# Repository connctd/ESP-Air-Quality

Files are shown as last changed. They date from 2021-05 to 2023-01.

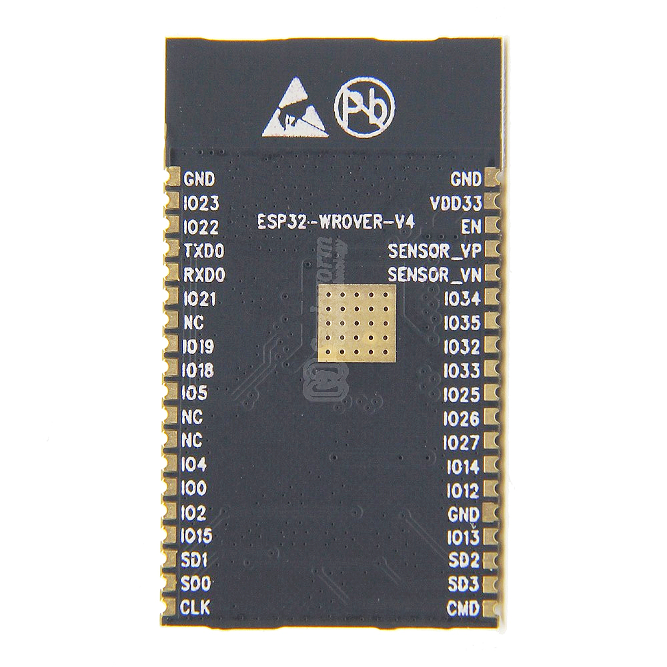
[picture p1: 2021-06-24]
hardware/ESP32-WROVER_pinout.jpeg

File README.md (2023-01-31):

# Airlytics Frame Manual

## Starting Sequence

After the system has been  powered up it tries to establish a connection with the WLAN. If a connection could be established, the first LED flashes green. If this was not possible, for example because no WiFi has been configured yet, the first LED lights up blue permanently and the System awaits to setup Wifi credentials (See setting up Wifi)

Afterwards, the sensor configuration is shown by the first 4 LEDs of the LED ring:

- First LED green, SCD30 installed and ready, otherwise white.
- Second LED green, BME680 installed and ready, otherwise white
- Third LED green, BME280 installed and ready, otherwise white
- Fourth LED green, SPS30 installed and ready, otherwise white

If all 4 LEDs are white, no sensor is installed or was found.

If the BME680 sensor is installed, it must first be adjusted so that usable values can be measured. This process can take up to 10min at the first start. If the calibration was completed successfully, it will not take so much time in the future. 

The same applies to the temperature values; these sensors generally need up to 15 minutes before the values reach their high precision.

## Setting Up the WiFi

When the system starts, it tries to connect to wifi which is indicated by an orange led. If ut cannot connect to the WIFI or no WIFI is configured yet, it automatically goes into the WIFI configuration mode, recognizable by a blue LED. You can also start the configuration mode manually by pressing and holding the button on the back for 5 seconds until the first LED lights up green. Then connect the smartphone (or PC) to the Network with the SSID "AirLytics Frame". You will be prompted to "Register to network". Follow this prompt and you will get to the configuration menu. Select the network from the list and enter the password, then press "Save". The system restarts and tries to log in to the network. If this is successful, the first LED flashes green, otherwise the network configuration starts over again and the steps must be repeated.

## Factory Reset
In order to reset the device to it's factory settings, the button on the back must be pressed for at least 15s. 

After 5s the first LED will light up green, after 12s it will light up red. After 15s it will blink red and the device will perform a factory reset. This will delete the network settings and the sensor settings like calibration data. 

# Error Handling

## Error Color Codes

Whenever an error occurs that was identified by the program, either the first LED or the gauge will blink 3 times in red color. Afterwards the first led or the whole gauge represents the error type by showing a solid color.

### First led blinks red, afterwards it shows a solid color

Indicates connection or general system errors. The following color code might give further details on the error type. 

| color | error |
| :--- | :--- |
| white | Error not further specified |
| blue | Error has to do with Wifi Connection |
| orange | Marconi Client could not be initialized. IP address could not resolved from URL or kind like that. |
| violette | Marconi Session could not be established. |
| red | EEPROM failure |

### Gauge blinks red, afterwards shows solid color

Indicates errors related to the connected sensors.

| color | error |
| :--- | :--- |
| white | Error not further specified |
| yellow | ERROR BME280 |
| orange | Error BME680 |
| violette | Error BSEC library |

# Airlytics Frame Debug Mode

The firmware (AirLyticsFrame_ESP/AirLyticsFrame_ESP.ino) has a debug flag. Setting it to true the errors described above will be more obvious (whole ring flashes). Also the frame reports property updates every 30s in debug mode. In normal mode the frame only reports updates every 2 minutes.

# Airlytics Frame Development

This section explains the development of the Airlytics firmware for an ESP32 with the Arduino IDE.   

There are 3 Arduino projects in this repository:
| Arduino Project | Description |
| :--- | :--- |
| Config-Flasher/Config-Flasher.ino | Software to flash device credentials (id and key) to the ESP32 EEPROM |
| SCD30_Calibration/SCD30_Calibration.ino | Software to calibrate the CO2 Sensor (SCD30) |
| AirLyticsFrame_ESP/AirLyticsFrame_ESP.ino | Firmware of the AirLytics Frame |

## Board Management

In order to install ESP32 extension to the Arduino IDE, add the line ```https://raw.githubusercontent.com/espressif/arduino-esp32/gh-pages/package_esp32_index.json``` to the additional board manager URL in the Arduino Settings. 

Open the Board Management and search for ```esp32```. Choose the version ```1.0.6``` developed by Espressif Systems and hit install. 

## Libraries

All libraries (except connctd Marconi) could be installed via the Library Management of Arduino IDE. In the menu bar go to ```Tools->Manage Libraries...``` and install the libraries below: 

| library | version | link |
| :--- | :--- | :--- |
| Wifi Manager | 2.0.4-beta  | https://github.com/tzapu/WiFiManager |
| Fast LED | 3.4.0 | https://github.com/FastLED/FastLED |
| Adafruit Unified Sensor | 1.1.4 | https://github.com/adafruit/Adafruit_Sensor |
| Adafruit BME280 | 2.1.3 | https://github.com/adafruit/Adafruit_BME280_Library |
| Adafruit SCD30 | 1.0.7 | https://github.com/adafruit/Adafruit_SCD30 |
| Bosh Sensortec | 1.6.1480 | https://github.com/BoschSensortec/BSEC-Arduino-library |
| connctd Marconi | | https://github.com/connctd/marconi-lib |
| ChaCha (marconi dep) | | https://github.com/OperatorFoundation/Crypto |
| ESP Coap (marconi dep)  | | https://github.com/connctd/ESP-CoAP |
| Sensirion SPS30 | 1.0.0 | https://github.com/Sensirion/arduino-sps |

### Installing connctd Marconi library

If you do not have git installed on your machine, please open the browser and and go to the [github page](https://github.com/connctd/marconi-lib). Press on ```Code``` and download the ZIP file. Extract the content to your Arduino libraries folder and restart Arduino IDE again. The macroni library shall now be available. 

If you have git installed, navigate to your Arduino IDE libraries folder and run the following command ```git clone https://github.com/connctd/marconi-lib```

### Modify platform.txt

The bsec library expects certain flags during compilation like mentioned here: https://github.com/BoschSensortec/BSEC-Arduino-library#3-modify-the-platformtxt-file Checkout the instructions. Alternatively you can do the following (but we cant guarantee that it works like that with later versions):

For **MacOS**, go to folder `~/Library/Arduino15/packages/esp32/hardware/esp32/1.0.6` and open `platform.txt`. Search for line

```
recipe.c.combine.pattern="{compiler.path}{compiler.c.elf.cmd}" {compiler.c.elf.flags} {compiler.c.elf.extra_flags} {compiler.libraries.ldflags} -Wl,--start-group {object_files} "{archive_file_path}" {compiler.c.elf.libs} {build.extra_libs} -Wl,--end-group -Wl,-EL -o "{build.path}/{build.project_name}.elf"
```

and change it to

```
recipe.c.combine.pattern="{compiler.path}{compiler.c.elf.cmd}" {compiler.c.elf.flags} {compiler.c.elf.extra_flags} -Wl,--start-group {object_files} "{archive_file_path}" {compiler.c.elf.libs} {compiler.libraries.ldflags} -Wl,--end-group -Wl,-EL -o "{build.path}/{build.project_name}.elf"
```

On **Windows** open: `c:\Users\YOURUSERNAME\AppData\Local\Arduino15\packages\esp32\hardware\esp32\1.0.6` and search for line starting with `recipe.c.combine.pattern`. In that line search for `-Wl`. Before that string add the following: `{compiler.libraries.ldflags}`. Resulting line should look like `recipe.c.combine.pattern [...] {build.extra_libs} {compiler.libraries.ldflags} -Wl [...]`

## Flashing the device credentials

Each Airlytics ESP device needs to authenticate itself with the backend by using a specific and unique device ID as well as a secret key. This has to be written to the EEProm of the ESP before the firmware will be flahed. In order to write the device credentials to the ESP EEProm, open the file ```Config-Flasher/Config-Flasher.ino```. 

In the setup section of the code, search for the line ```//deviceConfig = (DeviceConfig){ "<device id>", {<device secret in hex bytes>}};```. replace ```<device id>``` with the device ID you want to flash (IDs will be generated by connctd). 

Your device secret has to handled as hex byte array. There are several ways to generate a hex array of the base64 key. An easy way is to copy your secret key, go to [cryptii](https://cryptii.com/pipes/base64-to-hex), paste your key on the left box (If you do not follow the link, choose Decode, Base64 and the RFC 3548 variant ). A byte array will be calculated on the right. Copy the byte array and replace it with ```<device secret in hex bytes>```. Be aware of the C++ syntax for hex declaration (0x). 

Your final line should look like this (no valid id and secret used for the example):

    deviceConfig = (DeviceConfig){ "mku63nztfw0gn043", {0x41, 0xc6, 0x03, 0x2e, 0x15, 0xc2, 0xa8, 0xc4, 0x5f, 0x98, 0x96, 0x99, 0xf4, 0x6d, 0x7f, 0x46, 0x66, 0x14, 0x0a, 0x98, 0xde, 0x18, 0x64, 0xb2, 0xe9, 0x77, 0x55, 0xba, 0xdd, 0x50, 0xf1, 0xcf}};``` 
  
Transfer the code to your ESP. In the Serial Monitor, you'll might see something like: 

    Initialize EEPROM
    generating DeviceConfig object
    DeviceConfig generated
    DeviceID = mku63nztfw0gn043
    Device Key = 41 C6 33 2E ...
    Save device configuration ... OK
    Checking device Id ... OK
    Checking Device Key ... OK

    And done... Bye!

## Flashing the Airlytics firmware

In case you do not have flashed your device with the ```device id``` and ```device secret``` yet, please follow the steps for flashing the device credentials. 

Open the File ```AirLyticsFrame_ESP/AirLyticsFrame_ESP.ino``` and transfer it to your ESP. 

Your device is ready to use. 

## Calibrating the SCD30 manually

The program ```SCD30_Calibration``` allows the manual calibration of SCD30 CO2 Sensors. In general, this sensor has already been calibrated by the manufacturer. However, it may happen that this calibration is no longer valid. 
 
 There are two ways of calibrating the SCD30 with this program
       - place the sensor in an environment (outsite) with a CO2 value around 400ppm, wait until the measured CO2 value stabilizes and press the button 
       - place the sensor in an environment with a known CO2 value, wait until the measured CO2 value stabilizes and send the reference value via Serial. 
 
 The command to force the calibration is ```#cal:<your co2 value>$``` where ```<your co2 value>``` has to be replaced by an integer value 
 representing the reference value for your calibration. Example: in order to calibrate the SCD30 with a reference of 600ppm, you have to
 send ```#cal:600$```.

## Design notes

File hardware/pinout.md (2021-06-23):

# Pin Usage

## LEDs

* DATA IO25 (I2S available on this pin to make handling WS2812 etc. easier)
* U3 can be used to switch level shifter and direct connect to IO25 for the LEDs

## BME680

* SDA IO21
* SCL IO22
* SD0 IO19
* CS IO18

## SCD30

* SDA IO21
* SCL IO22
* RDY IO15
* SEL IO4

## User Button

* Button IO14 (pulling low with 10k resistor, debounced with 100nF and 1k)

## Board LEDs

* LED1 RX for the serial programmer
* LED2 TX for the serial programmer
* LED3 power indicator for USB-VCC

## GPIO

Contains 9 additional GPIO, I2C, GND, 3.3V and 5V marked on the board

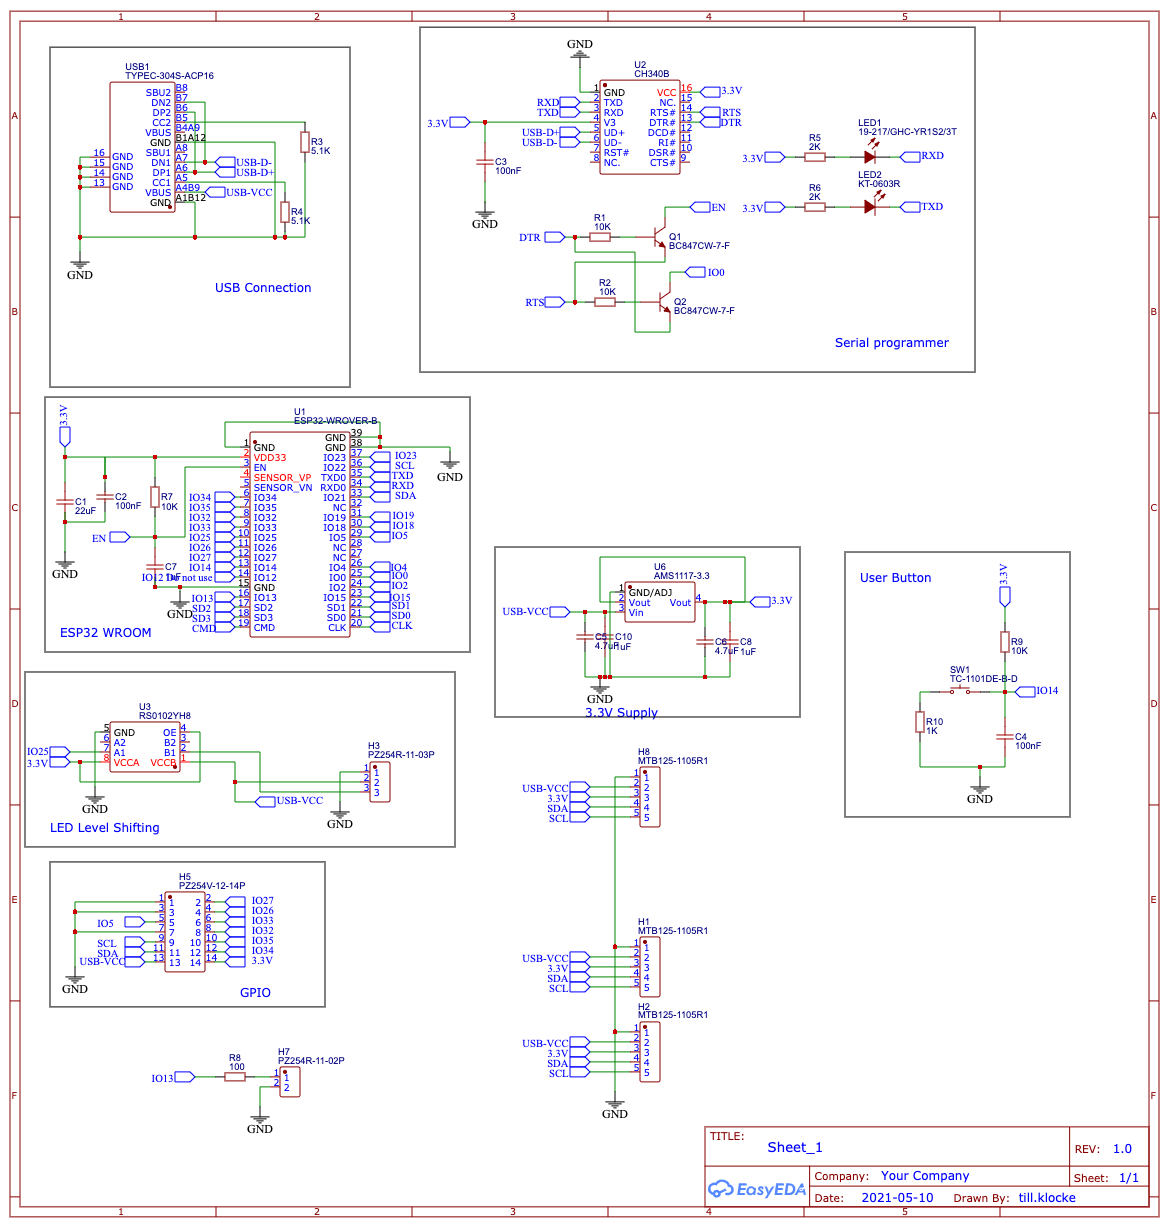
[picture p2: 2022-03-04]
hardware/Schematic.png

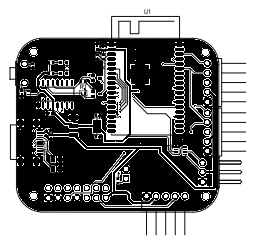
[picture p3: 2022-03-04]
hardware/pcb-image.png

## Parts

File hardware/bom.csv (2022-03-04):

ID | Name | Designator | Footprint | Quantity | Manufacturer Part | Manufacturer | Supplier | Supplier Part | Price
1 | MTB125-1105R1 | H1,H2,H8 | HDR-TH_5P-P2.54-H-M-W10.0 | 3 | MTB125-1105R1 | MINTRON | LCSC | C376123 | 0.037
2 | RS0102YH8 | U3 | SOT-23-8_L3.0-W1.7-P0.65-LS2.8-BL | 1 | RS0102YH8 | Jiangsu RUNIC Tech | LCSC | C783414 | 0.312
3 | PZ254R-11-02P | H7 | HDR-TH_2P-P2.54-H-M-W10.4 | 1 | PZ254R-11-02P | XFCN | LCSC | C492410 | 0.013
4 | 100 | R8 | R0402 | 1 | RC0402FR-07100RL | YAGEO | LCSC | C106232 | 0.001
5 | PZ254V-12-14P | H5 | HDR-TH_14P-P2.54-V-M-R2-C7-S2.54 | 1 | PZ254V-12-14P | XFCN | LCSC | C492424 | 0.073
6 | ESP32-WROVER-B | U1 | WIFIM-SMD_39P-L31.4-W18.0-P1.27 | 1 | ESP32-WROVER-B | Espressif Systems | LCSC | C503591 | 7.159
7 | TYPEC-304S-ACP16 | USB1 | USB-C-SMD_TYPEC-304S-ACP16 | 1 | TYPEC-304S-ACP16 | XUNPU | LCSC | C720630 | 0.274
8 | 100nF | C4,C3 | C0603 | 2 | CC0603KRX7R9BB104 | YAGEO | LCSC | C14663 | 0.002
9 | 10K | R9,R2,R1,R7 | R0402 | 4 | 0402WGF1002TCE | UniOhm | LCSC | C25744 | 0.001
10 | 1K | R10 | R0402 | 1 | 0402WGF1001TCE | UniOhm | LCSC | C11702 | 0.001
11 | TC-1101DE-B-D | SW1 | SW-TH_L6.1-W5.0-P5.00 | 1 | TC-1101DE-B-D | XKB Enterprise | LCSC | C561494 | 0.052
12 | PZ254R-11-03P | H3 | HDR-TH_3P-P2.54-H-M-W10.4 | 1 | PZ254R-11-03P | XFCN | LCSC | C492411 | 0.019
13 | CH340B | U2 | SOIC-16_L9.9-W3.9-P1.27-LS6.0-BL | 1 | CH340B | WCH | LCSC | C81010 | 1.408
14 | 5.1K | R4,R3 | R0805 | 2 | 0805W8F5101T5E | UniOhm | LCSC | C27834 | 0.003
15 | 19-217/GHC-YR1S2/3T | LED1 | LED0603-R-RD | 1 | 19-217/GHC-YR1S2/3T | EVERLIGHT | LCSC | C72043 | 0.03
16 | 2K | R6,R5 | R0402 | 2 | 0402WGJ0202TCE | UniOhm | LCSC | C25552
17 | KT-0603R | LED2 | LED0603-R-RD | 1 | KT-0603R | KENTO | LCSC | C2286
18 | 22uF | C1 | C0603 | 1 | CL10A226MQ8NRNC | SAMSUNG | LCSC | C59461 | 0.009
19 | 1uF | C7,C8,C10 | C0402 | 3 | CL05A105KA5NQNC | SAMSUNG | LCSC | C52923 | 0.003
20 | 100nF | C2 | C0402 | 1 | CL05B104KO5NNNC | SAMSUNG | LCSC | C1525 | 0.001
21 | BC847CW-7-F | Q2,Q1 | SC-70-3_L2.1-W1.3-P1.30-LS2.1-BR | 2 | BC847CW-7-F | DIODES | LCSC | C151600 | 0.041
22 | 4.7uF | C5,C6 | C0402 | 2 | CL05A475MP5NRNC | SAMSUNG | LCSC | C23733 | 0.005
23 | AMS1117-3.3 | U6 | SOT-223-3_L6.5-W3.4-P2.30-LS7.0-BR | 1 | AMS1117-3.3 | AMS | LCSC | C6186 | 0.164

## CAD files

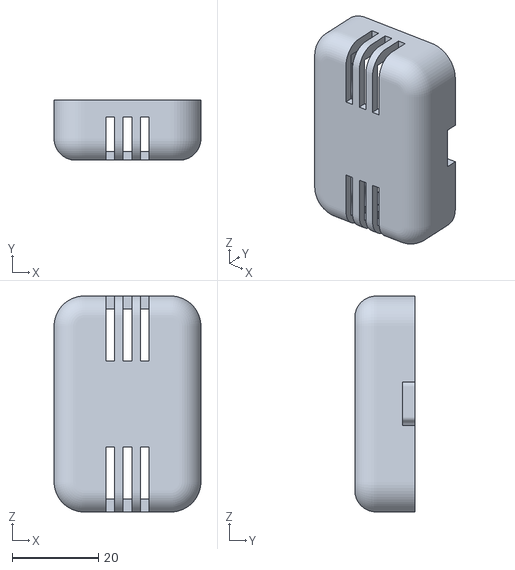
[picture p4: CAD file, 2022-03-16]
3D-Prints/Sensorbox_SCD30.stl
34.0 x 14.0 x 50.0

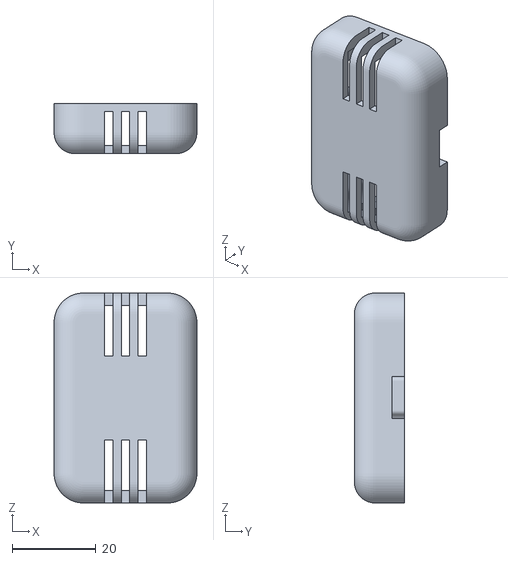
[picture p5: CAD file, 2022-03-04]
3D-Prints/Sensorbox_flat_SCD30.stl
34.0 x 12.0 x 50.0

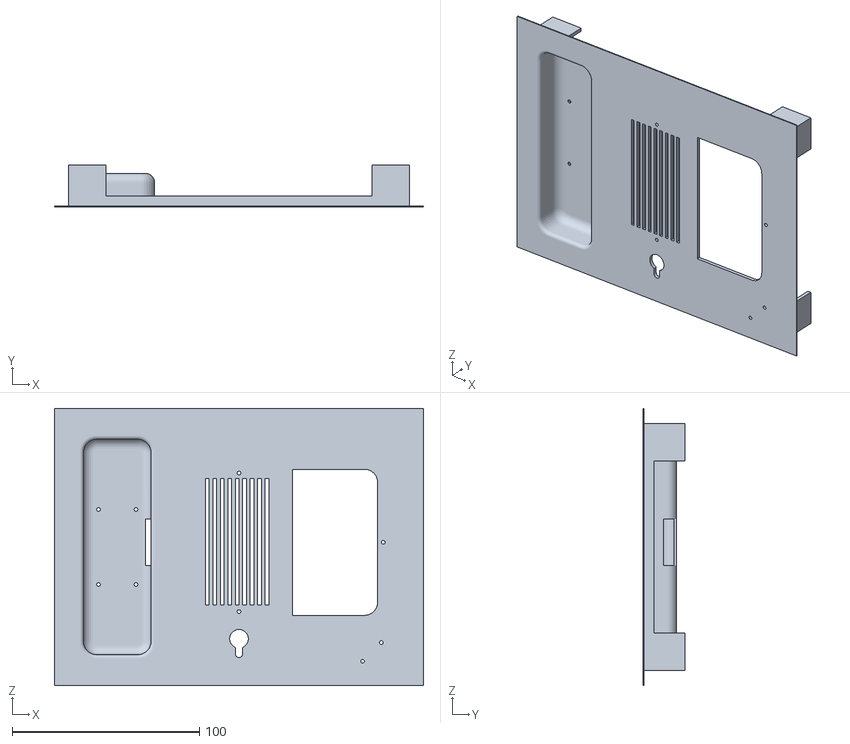
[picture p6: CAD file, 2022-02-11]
3D-Prints/Frame_co2_only.stl
197.0 x 22.5 x 148.0

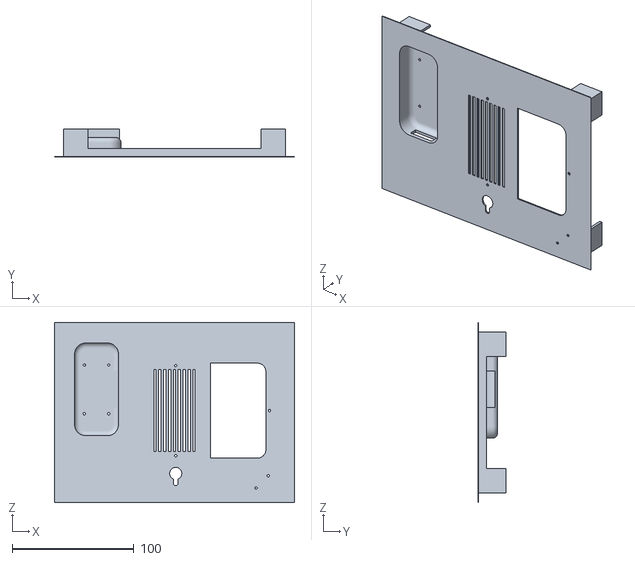
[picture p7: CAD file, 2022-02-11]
3D-Prints/Frame_co2_particle.stl
197.0 x 23.0 x 148.0

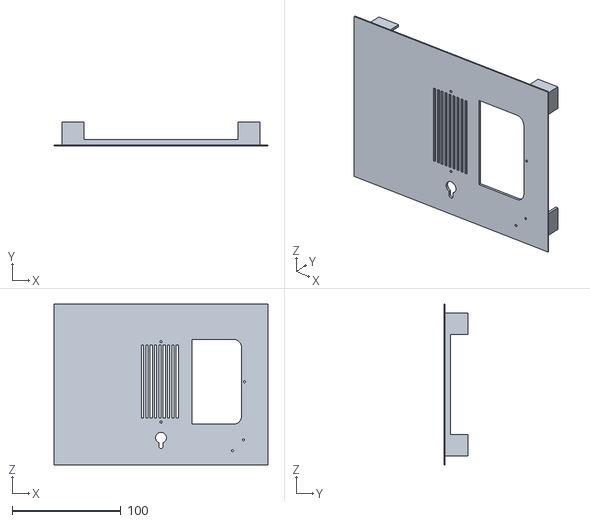
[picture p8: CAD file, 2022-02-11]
3D-Prints/Frame_no_sensor.stl
197.0 x 22.5 x 148.0

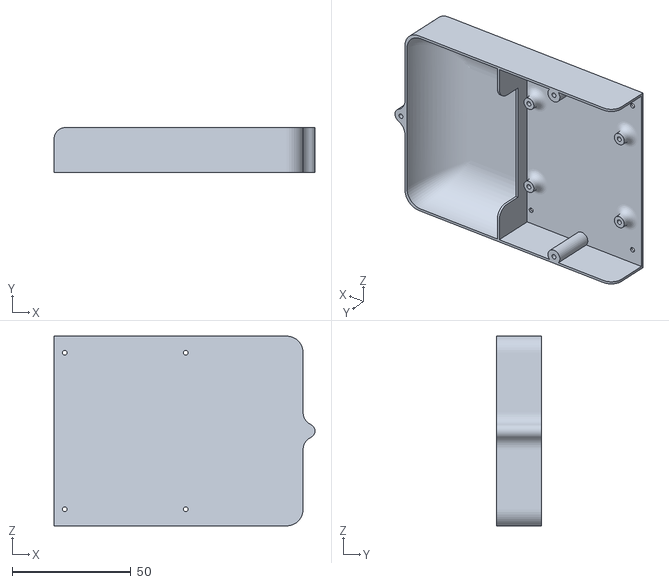
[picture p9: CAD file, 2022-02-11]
3D-Prints/PCB_Holder.stl
110.0 x 19.0 x 80.0

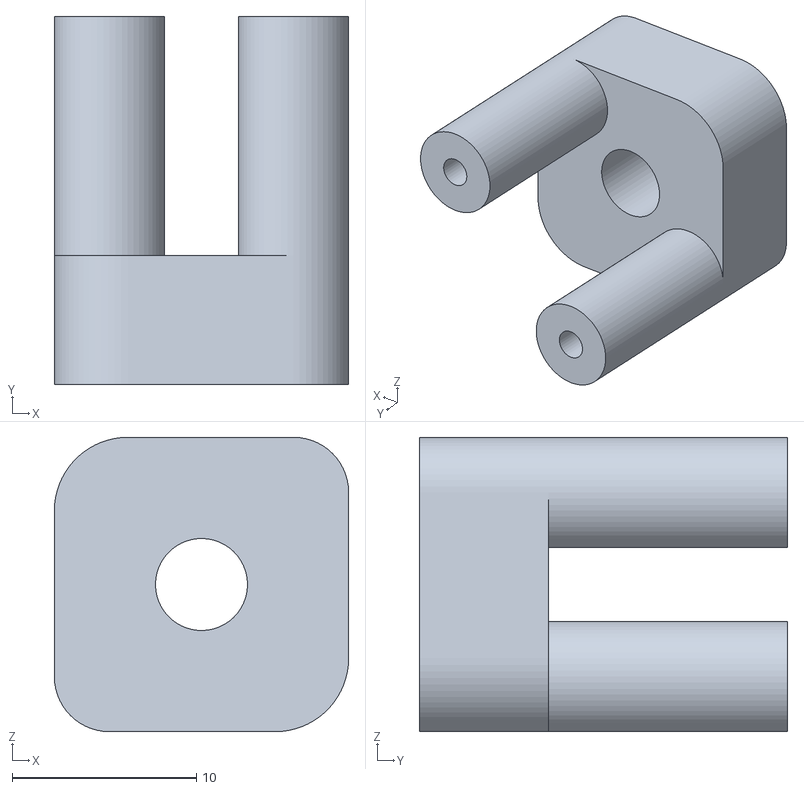
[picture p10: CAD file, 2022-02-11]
3D-Prints/LED_holder.stl
16.0 x 20.0 x 16.0

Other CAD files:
3D-Prints/AirLytics Frame v24.f3d

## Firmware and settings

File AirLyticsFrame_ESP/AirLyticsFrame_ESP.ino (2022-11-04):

/*
 *
 *  ----------------------------------------------------------------------------------------------------------------------
 *
 *                 _      _           _   _            ______                                   ______  _____ _____
 *           /\   (_)    | |         | | (_)          |  ____|                                 |  ____|/ ____|  __ \
 *          /  \   _ _ __| |    _   _| |_ _  ___ ___  | |__ _ __ __ _ _ __ ___   ___   ______  | |__  | (___ | |__) |
 *         / /\ \ | | '__| |   | | | | __| |/ __/ __| |  __| '__/ _` | '_ ` _ \ / _ \ |______| |  __|  \___ \|  ___/
 *        / ____ \| | |  | |___| |_| | |_| | (__\__ \ | |  | | | (_| | | | | | |  __/          | |____ ____) | |
 *       /_/    \_\_|_|  |______\__, |\__|_|\___|___/ |_|  |_|  \__,_|_| |_| |_|\___|          |______|_____/|_|
 *                               __/ |
 *                              |___/                                                                          IoT connctd
 *  ----------------------------------------------------------------------------------------------------------------------
 *
 *
 *           FileStructure ┐
 *                         ├ Variable Declaration ┐
 *                         |                      ├ Wifi
 *                         |                      ├ Gauge
 *                         |                      ├ Connctd / Coap
 *                         |                      ├ General
 *                         |                      └ Sensoring
 *                         ├ Setup
 *                         ├ The Loop
 *                         ├ System Functions
 *                         ├ Sensoring
 *                         ├ Connctd
 *                         └ Gauge / LED-Ring
 *
 *
 *
 *
 */


#include <EEPROM.h>
#include <Wire.h>
 // additional libraries
#include "marconi_client.h"   // https://github.com/connctd/marconi-lib                   communication with connctd backend
#include <FastLED.h>          // https://github.com/FastLED/FastLED                       LED-ring   
#include <WiFiManager.h>      // https://github.com/tzapu/WiFiManager                     configuration of WiFi settings via Smartphone
#include <Adafruit_Sensor.h>  // https://github.com/adafruit/Adafruit_Sensor              common library for arduino sensors
#include <Adafruit_BME280.h>  // https://github.com/adafruit/Adafruit_BME280_Library      library to work with BME280 sensors
#include <Adafruit_SCD30.h>   // https://github.com/adafruit/Adafruit_SCD30               library for SCD30 CO2 sensor
#include <sps30.h>
#include "bsec.h"             // https://github.com/BoschSensortec/BSEC-Arduino-library   library that works with a BME680 sensors and calculating CO2 equivalent


#define VERSION "1.0.69"  // major.minor.build   build will increase continously and never reset to 0, independend from major and minor numbers

// ++++++++++++++++++++ WIFI Management +++++++++++++++

WiFiManager wm;
WiFiManagerParameter custom_field;
const char* AP_SSID = "AirLytics Frame";
// ++++++++++++++++++++++ Gauge ++++++++++++++++++++
#define DEBUG false
#define LED_PIN   25
#define NUMPIXELS 13
#define ALLPIXELS 24
#define LED_TYPE    WS2811
#define COLOR_ORDER GRB

CRGB leds[ALLPIXELS];

int   animationSpeed = 50;
int   oldScaleValue = 1;     // needed for value change animation of gauge
int   gaugeValue = -1;    // how much percent of gauge should light up (from left to right); -1 means no value set from backend
float dimmLevel = 1.0F;  // value between 0 (off) and 1 (full brightness)

int notCalibratedAnimationState = 0;
unsigned long lastCalibrationAnimationStep = 0;

// +++++++++++++++++++++ CONNCTD Communication +++++++++++++++++++++

#define DEVICE_CONFIG_MEMORY_SIZE 0xFF

#define property_gauge         0x01
#define property_co2           0x02
#define property_temperature   0x03
#define property_humidity      0x04
#define property_dimmlevel     0x05
#define property_pressure      0x06
#define property_indicator     0x07
#define property_particle_1pm  0x08
#define property_particle_2pm5 0x09
#define property_particle_4pm  0x10
#define property_particle_10pm 0x11
#define property_particle_1nc  0x12
#define property_particle_2nc5 0x13
#define property_particle_4nc  0x14
#define property_particle_10nc 0x15


#define actionID_gaugeValue  0x01
#define actionID_dimmLevel   0x05
#define actionID_indicator   0x07

const char* marconiUrl = "marconi-udp.connectors.connctd.io";
IPAddress marconiIp;
int port = 5683;

MarconiClient* marconiClient;
bool marconiSessionInitialized = false;
bool marconiClientInitialized = false;
unsigned long resubscribeInterval = 60000; // in ms
unsigned long propertyUpdateInterval = 120000; // in ms, overwritten in debug mode
unsigned long lastResubscribe = 0; // periodically resubscribe
unsigned long lastInitTry = 0;
unsigned long lastPropertyUpdate = 0; // time when property updates were sent
unsigned long lastMarconiClientInitTry = 0;
unsigned long lastObservationOngoingEventReceived = 0;
unsigned long lastActionReceived = 0;
unsigned long observationTimeout = 1000 * 60 * 5; // max time with no observation ongoing -> will not receive any actions from backend
unsigned long intervalMarconiClientInit = 20000;
int marconiInitTryCnt = 0;
unsigned long actionReceiveTimeout = 1000 * 60 * 10; // 10 min


struct DeviceConfig {
  char id[DEVICE_ID_SIZE];
  unsigned char key[CHACHA_KEY_SIZE];
};
DeviceConfig deviceConfig;
EEPROMClass  deviceConfigMemory("devConfig", DEVICE_CONFIG_MEMORY_SIZE);
// +++++++++++++++++++++++ General +++++++++++++++++++++

#define TRIGGER_PIN 14
#define WARNING_PIN 13

#define ERR_GENERAL            0x00
#define ERR_NO_WIFI            0x01
#define ERR_NO_MARCONI_CLIENT  0x02
#define ERR_MARCONI_SESSION    0x03
#define ERR_EEPROM             0x04
#define ERR_NOT_FLASHED        0x05
#define ERR_REQUESTED_RESTART  0x06
#define ERR_WIRE               0xF0
#define ERR_BME680             0xF1
#define ERR_BSEC               0xF2
#define ERR_BME280             0xF3


#define WATCHDOG_TIMER         40 // 40 * 15s = 10min (600s)

bool warningLedOn = false;

int watchdogInterval = 15000; // 15s 
unsigned long lastWatchdogCheck = 0;
int watchDogCounter = WATCHDOG_TIMER; // will be decreased every watchdog Interval when bad behavior was detected
                                                  // system restarts when watchDogCounter reaches 0  
                                                  // will be set to WATCHDOG_TIMER when all conditions are fulfilled         

// +++++++++++++++++++++++ Sensoring +++++++++++++++++++
#define SDA                       21
#define SCL                       22
#define IAQA_NOT_CALIBRATED       0
#define IAQA_UNCERTAIN            1
#define IAQA_CALIBRATING          2
#define IAQA_CALIBRATION_COMPLETE 3

#define SEALEVELPRESSURE_HPA (1013.25)
#define TEMPERATURE_OFFSET -4.2

bool buttonPressed = false;
unsigned long buttonPressMillis = 0;

float temperature = 0.0;
float humidity = 0.0;
float pressure = 0.0;
int co2 = 0;

bool bme280_available = false;
bool bme680_available = false;
bool scd30_available = false;
bool sps30_available = false;

Adafruit_SCD30  scd30;
Adafruit_BME280 bme280;
Bsec iaqSensor;
int iaq_accuracy = IAQA_NOT_CALIBRATED;

EEPROMClass  bsecStateMemory("bsecState", BSEC_MAX_STATE_BLOB_SIZE + 1);  // status of BSEC library coul be stored in EEPROM when SCD30 was calibrated
uint8_t bsecState[BSEC_MAX_STATE_BLOB_SIZE] = { 0 };
bool periodicallyBsecSave = false; // periodically save the bsec state to EEPROM? will be addionally saved whenever bsec_accuracy switches to 1 or 3; 
unsigned long bsecStateUpdateInterval = 60 * 60 * 1000; // every 60min
unsigned long lastBsecUpdate = 0;
unsigned long lastValueChange = 0;
unsigned long valueChangeTimeout = 1000 * 60 * 10; // 10 min

struct sps30_measurement m;

// ++++++++++++++++++++++++++++++++++++++++++++++++++++++++++++++++++++++++++++++
//                                   SETUP
// ++++++++++++++++++++++++++++++++++++++++++++++++++++++++++++++++++++++++++++++
void setup() {
  marconiSessionInitialized = false;
  marconiClientInitialized = false;

  if (DEBUG) {
    propertyUpdateInterval = 30000;
  }

  Serial.begin(115200);

  initializeLedRing();
  initializeRandomSeed();
  initWarningLed();
  initTriggerButton();

  Serial.setDebugOutput(true);
  Serial.println("\n Starting");
  Serial.print("AirLytics - ESP v");
  Serial.println(VERSION);
  Serial.print("Debug enabled: ");
  Serial.println(DEBUG);

  bool ok = Wire.begin(SDA, SCL);
  //bool ok = Wire.begin();
  if (!ok) {
    // shit - this needs to be fixed due to a reset of Wire
    Serial.println("Setup wire failed");
    errorGauge(ERR_WIRE);
    while (true) {
      delay(1000);
    }
  }
  else {
    Serial.println("Wire setup was successful");
    Wire.setClock(50000L);
  }




  if (!initEEProm()) {
    Serial.println("ERROR - Failed to initialize EEPROM");
    Serial.println("ESP will be restarted");
    errorRing(ERR_EEPROM);
    restart();
  }

  if (!loadDeviceConfig()) {
    Serial.println("ERROR - Device was not flashed with Device ID and KEY!!!");
    while (true) {
      errorRing(ERR_NOT_FLASHED);
    }
  }

  initializeWiFi();

  if (!connectToWiFi()) {
    Serial.println("ERROR - Unable to connect to WiFi");
    Serial.println("System will restart now");
    errorRing(ERR_NO_WIFI);
    restart();
  }

  marconiClientInitialized = initMarconi();

  // try to 
  initSensors();

  refreshGauge();
}

void initSensors() {
  sps30_available = initSPS30();
  delay(1000);
  bme680_available = initBME680();
  delay(1000);
  bme280_available = initBME280();
  delay(1000);
  scd30_available = initSCD30();
  delay(1000);
  // show status about sensors that have been found  
  sensorInfo();
}

void initWarningLed() {
  pinMode(WARNING_PIN, OUTPUT);
  digitalWrite(WARNING_PIN, false);
}


void initTriggerButton() {
  pinMode(TRIGGER_PIN, INPUT);
}

void initializeRandomSeed() {
  //srand(ESP8266TrueRandom.random()); ‚
  srand(analogRead(0));  // this one will not work on ESP8266!!
}

void initializeLedRing() {
  FastLED.addLeds<LED_TYPE, LED_PIN, COLOR_ORDER>(leds, ALLPIXELS).setCorrection(TypicalLEDStrip);
  FastLED.setBrightness(255);
  clearRing();
}

bool initMarconi() {
  Serial.println("initialize Marconi Library");
  marconiInitTryCnt++;
  lastMarconiClientInitTry = millis();
  if (!resolveMarconiIp()) {
    Serial.println("ERROR, unable to initialize Marconi library");
    return false;
  }
  marconiClient = new MarconiClient(marconiIp, port, deviceConfig.id, deviceConfig.key, onConnectionStateChange, onDebug, onErr);
  marconiInitTryCnt = 0;
  return true;
}

bool initEEProm() {
  bool res = deviceConfigMemory.begin(DEVICE_CONFIG_MEMORY_SIZE);
  res = res && bsecStateMemory.begin(BSEC_MAX_STATE_BLOB_SIZE + 1);
  return res;
}

// ++++++++++++++++++++++++++++++++++++++++++++++++++++++++++++++++++++++++++++++
//                                    THE LOOP 
// ++++++++++++++++++++++++++++++++++++++++++++++++++++++++++++++++++++++++++++++

void loop() {
  checkButton();        // check wether trigger button was pressed    
  watchdog(millis());   // trigger the watchdog routine

  if (bme680_available) {
    // do not do other stuff when calibrating -> high probability for calibration failure
    if (iaq_accuracy != IAQA_NOT_CALIBRATED) {
      doMarconiStuff(millis());  // communication stuff with connctd library
    }
  }
  else {
    doMarconiStuff(millis());  // communication stuff with connctd library
  }

  doSensorStuff(millis());  // read sensor values

  // and wait for 10ms
  delay(10);
}

void watchdog(unsigned long currTime) {

  if (gaugeValue == -255) {
    Serial.println("");
    Serial.println("======= WATCHDOG =======");
    Serial.println("    Requested Restart");
    Serial.println("System will restart now!");
    Serial.println("========================");
    Serial.println("");
    Serial.println("");
    errorRing(ERR_REQUESTED_RESTART);
    restart();
    return;
  }

  // when there is nothing to check, return
  if (currTime - lastWatchdogCheck < watchdogInterval) {
    return;
  }

  // time to check conditions again
  lastWatchdogCheck = currTime;
  // when watchdog is active and time is up, restart everything
  if (watchDogCounter <= 0) {
    Serial.println("");
    Serial.println("======= WATCHDOG =======");
    printWatchdogStatus();
    Serial.println("------------------------");
    Serial.println("System will reboot now!");
    Serial.println("========================");
    Serial.println("");
    Serial.println("");
    restart();
  }

  // check all conditions. either start or stop the watchdog
  if ((isActionTimeout()) || (isValueChangeTimeout()) || (gaugeValue < 0) || (!marconiSessionInitialized) || (!marconiClientInitialized) || (isObservationTimeout())) {
    // watchdog activation? or was it activated already?
    if (watchDogCounter == WATCHDOG_TIMER) {
      // watchdog activation, print current status
      Serial.println("============ WATCHDOG ===========");
      printWatchdogStatus();
      Serial.println("================================");
    }
    watchDogCounter--;
  }
  else {
    if (watchDogCounter < WATCHDOG_TIMER) {
      Serial.println("============ WATCHDOG ===========");
      Serial.println("Watchdog Countdown Reset - everything seems to be fine");
      Serial.println("================================");
    }
    watchDogCounter = WATCHDOG_TIMER;
  }

}

void printWatchdogStatus() {
  Serial.println("Watchdog active, countown is running");
  Serial.print("ValueChangeTimeout        : ");
  Serial.println(isValueChangeTimeout());
  Serial.print("GaugeValue                : ");
  Serial.println(gaugeValue);
  Serial.print("marconiClientInitialized  : ");
  Serial.println(marconiClientInitialized);
  Serial.print("marconiSessionInitialized : ");
  Serial.println(marconiSessionInitialized);
  Serial.print("observation timeout       : ");
  Serial.println(isObservationTimeout());
  Serial.print("action timeout            : ");
  Serial.println(isActionTimeout());
}

// Do everything that is needed for the communication with the connctd backend
void doMarconiStuff(unsigned long currTime) {

  // check if client is initialized
  if (!marconiClientInitialized) {
    if (currTime - lastMarconiClientInitTry > intervalMarconiClientInit) {
      if (!initMarconi() && (marconiInitTryCnt >= 5)) {
        //errorRing(ERR_NO_MARCONI_CLIENT);  // this is confusing for the user
      }
      if (!initMarconi() && (marconiInitTryCnt >= 10)) {
        errorRing(ERR_NO_MARCONI_CLIENT);
        restart();
      }
    }
    return;
  }

  marconiClient->loop();
  currTime = millis();

  if (!marconiSessionInitialized) {
    if (currTime - lastInitTry > 10000) {
      lastInitTry = currTime;
      initMarconiSession();
      if (marconiInitTryCnt >= 3) {
        Serial.print("Unable to initialize Session. Try ");
        Serial.print(marconiInitTryCnt);
        Serial.println("/10");
        errorRing(ERR_MARCONI_SESSION); // this is confusing for the user
      }
      if (marconiInitTryCnt >= 10) {
        Serial.println("Unable to initialize Session, System will reboot now");
        errorRing(ERR_MARCONI_SESSION);
        restart();
      }
    }
    return;
  }


  if (currTime - lastObservationOngoingEventReceived > observationTimeout) {
    Serial.println("Observation Timeout - System tries to init session again.");
    marconiSessionInitialized = false;
    lastResubscribe == 0;
    refreshGauge();
    return;
  }


  if (currTime - lastResubscribe > resubscribeInterval || lastResubscribe == 0) {
    lastResubscribe = currTime;
    marconiClient->subscribeForActions(onAction);
  }


  if ((gaugeValue >= 0) && (currTime - lastObservationOngoingEventReceived > (observationTimeout / 2))) {
    Serial.println("Connection seems to be lost. Did not received event 'Observation Ongoing'");
    Serial.println("Gauge will be disabled by setting color to white");
    //marconiSessionInitialized = false;         
    gaugeValue = -1;
    refreshGauge();
  }



  // periodically send property updates
  if (currTime - lastPropertyUpdate > propertyUpdateInterval) {
    Serial.println("Sending Properties Update");
    lastPropertyUpdate = currTime;
    sendGaugeDimmLevelValue();
    sendWarningLedState();
    if (sensorsAvailable()) {
      if (scd30_available) {
        if (scd30.dataReady()) {
          if (!scd30.read()) {
            Serial.println("Error reading SCD30 data");
          }
        }
      }
      readTemperatureHumidity();
      // readTemperature();
      // readHumidity();
      readPressure();
      //adjustTemperature(); 
      Serial.println("Sending property values");
      sendTemperatureValue();
      sendHumidityValue();
      sendPressureValue();
      if (sps30_available) {
        readParticles();
        sendParticleValues();
      }
      if (readCo2()) {
        sendCo2Value();
      }
      else {
        if (readCo2Equivalent()) {
          sendCo2Value();
        }
      }
    }
  }

}

void doSensorStuff(unsigned long currTime) {
  // BME680/BSEC stuff
  if (bme680_available) {
    if (!checkIaqSensorStatus()) {
      evalIaqSensorStatus();


    }
    if (periodicallyBsecSave) {
      if (currTime - lastBsecUpdate > bsecStateUpdateInterval) {
        saveBsecState();
        lastBsecUpdate = currTime;
      }
    }
    // periodicaly trigger iaqSensor
    if (iaqSensor.run()) {
      // in case new data is available
      printIAQdata();
      evalIaqAccuracy();
    }
    else {
      // iaqSensor.run() could be false when no new data available or when an error occurs
      // need to check the status for this.   
      if (!checkIaqSensorStatus()) {
        while (true) {
          errorGauge(ERR_BSEC);
        }
      }
    }
    // trigger animation when sensor is calibrating, do not animate when button is pressed
    if ((!isIaqCalibrated()) && (!buttonPressed)) {
      if (currTime - lastCalibrationAnimationStep > animationSpeed) {
        triggerNotCalibratedAnimation();
        lastCalibrationAnimationStep = currTime;
      }
    }
  }



}


// ++++++++++++++++++++++++++++++++++++++++++++++++++++++++++++++++++++++++++++++
//                                 System Functions
// ++++++++++++++++++++++++++++++++++++++++++++++++++++++++++++++++++++++++++++++


bool loadDeviceConfig() {
  Serial.println("reading device configuration");

  deviceConfigMemory.get(0, deviceConfig);
  Serial.print("Device ID = ");
  Serial.println(deviceConfig.id);
  Serial.print("Device ID: ");
  for (int i = 0; i < DEVICE_ID_SIZE; i++) {
    Serial.print(deviceConfig.id[i], HEX);
    Serial.print(" ");
  }
  Serial.println();
  Serial.print("last 5 bytes of Device Key: ");
  for (int i = CHACHA_KEY_SIZE - 5; i < CHACHA_KEY_SIZE; i++) {
    Serial.print(deviceConfig.key[i], HEX);
    Serial.print(" ");
  }
  Serial.println();

  return ((deviceConfig.id[0] != 0xFF) && (deviceConfig.id[0] != 0));
}

void resetToFactorySettings() {
  Serial.println("!!!!!!!!!!!!  Performing Factory Reset  !!!!!!!!!!!!!");
  Serial.println("Deleting Wifi Settings");
  wm.resetSettings();
  eraseBsecState();
}

// ++++++++++++++++++++++++++++++++++++++++++++++++++++++++++++++++++++++++++++++
//                                    Sensoring
// ++++++++++++++++++++++++++++++++++++++++++++++++++++++++++++++++++++++++++++++

// ++++++++++++++++++++++++++++++++++++ SPS30 +++++++++++++++++++++++++++++++++++


bool initSPS30() {
  int16_t ret;
  sensirion_i2c_init();
  int cnt = 0;
  Serial.print("Initializing SPS30 .... ");
  while (sps30_probe() != 0) {
    // Serial.print("SPS sensor probing failed\n");
    delay(500);
    cnt++;
    if (cnt > 2) {
      Serial.println("ERROR - SPS sensor probing failed");
      return false;
    }
  }
  Serial.println("OK");

  ret = sps30_set_fan_auto_cleaning_interval_days(4);
  if (ret) {
    Serial.print("ERROR, unable to set the auto-clean interval: ");
    Serial.println(ret);
    return false;
  }

  // start measuring
  ret = sps30_start_measurement();
  if (ret < 0) {
    Serial.println("ERROR, starting measurement\n");
  }

  return true;
}

// +++++++++++++++++++++++++++++++ BME680 / BSEC ++++++++++++++++++++++++++++++++

bool initBME680() {
  Serial.print("Initializing BME680 ... ");
  //iaqSensor.begin(BME680_I2C_ADDR_SECONDARY,Wire);  

  int address = 0x76;
  // check for address 0x77 

  Wire.beginTransmission(address);
  if (Wire.endTransmission() != 0) {
    address = 0x77;
    Wire.beginTransmission(address);
    if (Wire.endTransmission() != 0) {
      Serial.println("ERROR");
      return false;
    }
  }

  iaqSensor.begin(address, Wire);
  if (!checkIaqSensorStatus()) {
    Serial.println("ERROR");
    evalIaqSensorStatus();
    return false;
  }

  bsec_virtual_sensor_t sensorList[10] = {
    BSEC_OUTPUT_RAW_TEMPERATURE,
    BSEC_OUTPUT_RAW_PRESSURE,
    BSEC_OUTPUT_RAW_HUMIDITY,
    BSEC_OUTPUT_RAW_GAS,
    BSEC_OUTPUT_IAQ,
    BSEC_OUTPUT_STATIC_IAQ,
    BSEC_OUTPUT_CO2_EQUIVALENT,
    BSEC_OUTPUT_BREATH_VOC_EQUIVALENT,
    BSEC_OUTPUT_SENSOR_HEAT_COMPENSATED_TEMPERATURE,
    BSEC_OUTPUT_SENSOR_HEAT_COMPENSATED_HUMIDITY,
  };

  iaqSensor.updateSubscription(sensorList, 10, BSEC_SAMPLE_RATE_LP);

  if (!checkIaqSensorStatus()) {
    Serial.println("ERROR");
    evalIaqSensorStatus();
    return false;
  }

  Serial.println("OK");
  String output = "BSEC library version " + String(iaqSensor.version.major) + "." + String(iaqSensor.version.minor) + "." + String(iaqSensor.version.major_bugfix) + "." + String(iaqSensor.version.minor_bugfix);
  Serial.println(output);

  loadBsecState();
  return true;
}

bool checkBsecState() {
  for (uint8_t i = 0; i < BSEC_MAX_STATE_BLOB_SIZE; i++) {
    if (bsecState[i] != 0xFF) {
      return true;
    }
  }
  return false;
}

bool sensorsAvailable() {
  return bme280_available || bme680_available || scd30_available || sps30_available;
}
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

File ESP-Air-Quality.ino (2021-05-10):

/*
 * 
 *  ----------------------------------------------------------------------------------------------------------------------
 *                          _   ___ ___    ___  _   _  _   _    ___ _______   __  ___ ___ ___ 
 *                         /_\ |_ _| _ \  / _ \| | | |/_\ | |  |_ _|_   _\ \ / / | __/ __| _ \
 *                        / _ \ | ||   / | (_) | |_| / _ \| |__ | |  | |  \ V /  | _|\__ \  _/
 *                       /_/ \_\___|_|_\  \__\_\\___/_/ \_\____|___| |_|   |_|   |___|___/_|  
 *  ----------------------------------------------------------------------------------------------------------------------                          
 *  
 * 
 *           FileStructure ┐
 *                         ├ Variable Declaration ┐
 *                         |                      ├ WiFi Management 
 *                         |                      ├ Gauge
 *                         |                      ├ Connctd / Coap
 *                         |                      ├ General
 *                         |                      └ Sensoring
 *                         ├ Setup
 *                         ├ The Loop
 *                         ├ System Functions
 *                         ├ Sensoring
 *                         ├ Connctd
 *                         ├ WiFi Management 
 *                         └ Gauge / LED-Ring
 * 
 * 
 */



#include <ESP8266WiFi.h>
#include <Adafruit_NeoPixel.h>
#include <WiFiManager.h> // https://github.com/tzapu/WiFiManager
#include <ArduinoJson.h>
#include <ESP8266TrueRandom.h>
#include "coap_client.h"
#include <EEPROM.h>
#include <Wire.h>
#include <SPI.h>
#include <Adafruit_Sensor.h>
#include <Adafruit_BME280.h>

// ++++++++++++++++++++ WIFI Management +++++++++++++++

#define TRIGGER_PIN D6
WiFiManager wm; 
WiFiManagerParameter custom_field; 
const char* AP_SSID = "Air-Quality";
  

// ++++++++++++++++++++++ Gauge ++++++++++++++++++++
#define LED_PIN   D4
#define NUMPIXELS 13
#define ALLPIXELS 28


Adafruit_NeoPixel pixels = Adafruit_NeoPixel(ALLPIXELS,LED_PIN, NEO_GRB + NEO_KHZ800);

int animationSpeed = 50;  
int oldScaleValue = 1;     // needed for value change animation of gauge
int gaugeValue = 0;
float brightness = 1.0F;   // value between 0 (off) and 1 (full brightness)

// +++++++++++++++++++++++ Connctd +++++++++++++++++++++

coapClient coap;
IPAddress ip(35,205,82,53);
StaticJsonDocument<200> jsonDoc;
int port = 5683;
char* actionPath = " api/v1/devices/xxxxxxxx/xxxx/action";
char* propertyPath = " api/v1/devices/xxxxxxxx/xxxx/status";

struct DeviceConfig {    
    char id[9];     // need one char more for String termination
    char code[5];   // same here 
} deviceConfig;


// +++++++++++++++++++++++ General +++++++++++++++++++++
unsigned int loopCnt = 0;


// +++++++++++++++++++++++ Sensoring +++++++++++++++++++

#define SEALEVELPRESSURE_HPA (1013.25)

Adafruit_BME280 bme; 

bool buttonPressed = false;
unsigned long buttonPressMillis = 0;

float temperature = 0.0;
float humidity = 0.0;
float pressure = 0.0;

bool sensorsAvailable = false;
// ++++++++++++++++++++++++++++++++++++++++++++++++++++++++++++++++++++++++++++++
//                                   SETUP
// ++++++++++++++++++++++++++++++++++++++++++++++++++++++++++++++++++++++++++++++

void setup() {
  
  Serial.begin(115200);
  Serial.setDebugOutput(true);   
  Serial.println("\n Starting");

  pinMode(TRIGGER_PIN, INPUT);

  EEPROM.begin(512);

  initializeRandomSeed();
  initializeLedRing();   
  initializeWiFi(); 
  
  // ToDo - make non blocking and animate "connecting gauge"
  if (!connectToWiFi()){    
    ESP.restart();
  }

  loadDeviceConfig();
  clearRing();
  initializeCoapClient();

  sensorsAvailable = initBME280();  
}

void initializeRandomSeed(){
    srand(ESP8266TrueRandom.random());
}

void initializeLedRing(){
  pixels.begin(); 
  clearRing();  
}

void initializeCoapClient(){
  buildPaths();
  coap.start(port);    
  coap.response(onServerMessage);
}


// ++++++++++++++++++++++++++++++++++++++++++++++++++++++++++++++++++++++++++++++
//                                    THE LOOP 
// ++++++++++++++++++++++++++++++++++++++++++++++++++++++++++++++++++++++++++++++

void loop() {
  checkButton(); // check wether trigger button was pressed  

  if ((loopCnt % 5000) == 0){ // every 50s
    registerForAction();
  }

  if ((loopCnt % 3000) == 0){  // every 30s        
    sendCo2Value();    
    sendGaugeBrightnessValue();
    if (sensorsAvailable) {
       if (readTemperature()){
        sendTemperatureValue();
      }
      if (readHumidity()){
        sendHumidityValue();
      }
      if (readPressure()){
        sendPressureValue();
      }
    }
  }
  
  coap.loop();
  loopCnt++;

  
  if (loopCnt > 65535){ // when 16bit max have been reached - do not care about 32bit systems
    loopCnt = 0;
  }
  
  delay(10);

}



// ++++++++++++++++++++++++++++++++++++++++++++++++++++++++++++++++++++++++++++++
//                                 System Functions
// ++++++++++++++++++++++++++++++++++++++++++++++++++++++++++++++++++++++++++++++


void loadDeviceConfig(){
   Serial.println("Loading device settings"); 
   EEPROM.get(0,deviceConfig);    
   Serial.print("Device ID ");
   Serial.println(deviceConfig.id);   
}


void saveDeviceConfig(){
  EEPROM.put(0, deviceConfig);
  if (EEPROM.commit()) {
     Serial.println("Device configuration saved");
  } else {
     Serial.println("EEPROM error - Device Id and Device Code could not be saved");
     errorRing();
  }
}

void checkButton(){  
  
  if(isButtonPressed()){     
      if (!buttonPressed){ 
        onButtonPressed();
      } 
  }    

  if (buttonPressed) {
    if (!isButtonPressed()){
        onButtonReleased();
        return;
    }    
    long pressedMillis = millis() - buttonPressMillis;
    if(pressedMillis >= 15000){
      errorRing();
      resetConfiguration();
      ESP.restart();
      return;
    }
    if(pressedMillis >= 10000){
      redRing();
      return; 
    }
    if (pressedMillis >= 5000){
      greenRing();
    }
  }
}


void onButtonPressed(){
   Serial.println("Button pressed");
   buttonPressed = true;
   buttonPressMillis = millis();         
}

void onButtonReleased(){
   long pressedMillis = millis() - buttonPressMillis;
 
   buttonPressed = false;
  
   Serial.print("Button released (");
   Serial.print(pressedMillis);
   Serial.println("ms)");  

   if (pressedMillis <= 1500) {   
      triggerGaugeBrightness();
      return;
   }
   if ((pressedMillis >= 5000) && (pressedMillis < 10000)){
        startWiFiConfiguration(120);       
   }
   clearRing();
   refreshGauge();
}

void resetConfiguration(){
   Serial.println("Resetting Configuration");
   wm.resetSettings();

  // TODO - delete EEPROM
}


// ++++++++++++++++++++++++++++++++++++++++++++++++++++++++++++++++++++++++++++++
//                                    Sensoring
// ++++++++++++++++++++++++++++++++++++++++++++++++++++++++++++++++++++++++++++++
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

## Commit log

2021-05-07 * device configuration will be set in Wifi configuration menue and stored in EEPROM
2021-05-07 * ESP measures temperature, humidity, pressure with BME280 over i2c now
2021-05-10 * fixed action selection
    [ESP-Air-Quality.ino]
2021-05-10 * button could be used as brightness trigger * optimized button reaction for config etc.. * minor code refactoring
2021-05-12 Added exports from EasyEDA which should enable reimport into EasyEDA as well as production of the hardware
    [bom.csv, pnp.csv]
2021-05-17 Replaced IO2 with IO4 to avoid problems with using a strapping pin with external hardware
    [pnp.csv]
2021-06-15 started but not finished, buggy
    [ESP-Air-Quality.ino]
2021-06-17 * fixed merging bugs, marconi library integrated.
    [ESP-Air-Quality.ino]
2021-06-17 changes do deviceConfig
2021-06-17 * wtf... compiling issues -> trying on another machine that's why I need to commit shitty code
    [ESP-Air-Quality.ino]
2021-06-17 software is not working with ESP hardware library 3.0.0, code works fine
    [Config-Flasher.ino, ESP-Air-Quality.ino]
2021-06-18 * fixed too fast init. need to wait for server response
    [ESP-Air-Quality.ino]
2021-06-18 fixed marconi version issues
    [ESP-Air-Quality.ino]
2021-06-22 * problems with EEPROM :( Config Flasher works fine, Air-Quality raises exception on deviceConfigMemory.begin
    [Config-Flasher.ino, ESP-Air-Quality.ino]
2021-06-22 * fixed EEPROM issue
    [ESP-Air-Quality.ino]
2021-06-22 * still serious EEPROM issues
    [Config-Flasher.ino, ESP-Air-Quality.ino]
2021-06-22 * adjusted PINs to connctd-Board
2021-06-22 * fixed pins, everything works fine :)
    [ESP-Air-Quality.ino]
2021-06-23 * everything fixed :)
    [Config-Flasher.ino]
2021-06-24 * changed LED library, now using FastLED
2021-06-25 * fixed bug on WifiManagement. ESP restarted after Wifi-Config was pressed
    [ESP-Air-Quality.ino]
2021-06-25 * added EEPROM check when device configuration was read
2021-06-30 * set new device id for ESP "Matze" * fixed gauge bug
    [Config-Flasher.ino, ESP-Air-Quality.ino]
2021-06-30 * fixed minor bug * added feature for setDimmLevel via API
    [Config-Flasher.ino, ESP-Air-Quality.ino]
2021-07-05 * bme680 calibration works now * no sensor detection implemented * minor refactorings
2021-07-08 * added not calibrated animation
2021-07-08 * optimized calibration handling, new values will be sent immediately
2021-07-09 * implemented save calibration data, but not set after loading
2021-07-09 * fixed heavy bug that found its way into the code with the last commit
    [ESP-Air-Quality.ino]
2021-07-09 * implemented indicator LED support
2021-07-12 * code cleaning, * adjusted preriodically bsec state saving to proper interval * better warning-led_integration. LED is blinking 5 times when warning became true
2021-07-14 * added Color codes to LED-Ring
2021-07-15 * sensor was calibrating very often at runtime, success-gauge was confusing. Sucess-gauge only appears now, when accuracy switches from 0 to 1
2021-07-16 * updated readme * implemented indicator for installed sensor type
2021-07-21 * fixed bug -> unable to send co2 values * minor changes
    [ESP-Air-Quality.ino]
2021-07-24 * set LED Gauge to 13 LEDs * removed valid key and device id from Config Flasher code
2021-08-16 * added temperature offset of -4.2°C
2021-08-25 fixed minor bug, lastObservationOngoingEvent was not reset when session was initialized.
    [ESP-Air-Quality.ino]
2021-08-25 - added missing action request to watchdog
    [ESP-Air-Quality.ino]
2021-10-20 - fixed not calibrated animation - fixed eeprom erasing due to factory reset - no communication due to calibration to prevent calibration faults
    [ESP-Air-Quality.ino]
2021-10-21 added red blinking for factory reset
    [ESP-Air-Quality.ino]
2022-01-12 added multiple address support for BME680 sensors
2022-02-11 added 3D print files for picture frame
    [Frame_co2_only.stl, Frame_co2_particle.stl, Frame_no_sensor.stl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]
2022-02-18 changed Ascii-Art to AirLytics Frame - ESP
2022-02-18 deleted that shit
    [pnp.csv]
2022-02-22 Added submodule for Adafruit unified sensor library in version 1.1.4
2022-02-22 Added submdoule for Adafruit BM280 sensor library in version 2.1.3
2022-02-22 Added submodule for BSEC arduino library in version 1.6.1480
2022-02-22 Added submodule for arduino sps30 library in version 1.0.0
2022-02-22 Added makefile to build project via arduino-cli
2022-02-22 Updated README with updated instructions on how to get the BSEC lib working on current arduino environments with the ESP32 core
2022-02-22 Added library BusIO since the SCD30 driver depends on it
2022-02-25 added new STL file for sensorbox
    [Sensorbox_flat_SCD30.stl]
2022-02-25 Added production files for revision 1 pcb
    [bom.csv, pnp.csv]
2022-03-04 adjusted height of sensorbox
    [Sensorbox_flat_SCD30.stl]
2022-03-10 added minimal calibration program in order to recalibrate SCD30 to reference of 400ppm
2022-03-15 added 3d files for fusion 360
    [AirLytics Frame v24.f3d]
2022-03-16 changed model of Sensorbox
    [Sensorbox_SCD30.stl]
2022-03-16 added section for flashing the device credentials
2022-03-18 - added calibration via serial command - code refactoring
2022-03-23 added full stop when Wire can't be initialized to force the user to reconnect the power plug
2022-04-04 Reset scd30 before restart
    [AirLyticsFrame_ESP.ino]
2022-05-20 fixed humidity and temperature accuracy
    [AirLyticsFrame_ESP.ino]
2022-06-09 fixed high humidity bug. It was possible to reach humidity values above 100% due to humidity adjustment
    [AirLyticsFrame_ESP.ino]
2022-10-20 Print version etc. a couple of ticks later otherwise it might get lost
2022-10-21 Using two leds in case something went wrong with sensors
    [AirLyticsFrame_ESP.ino]
2022-10-21 Disable single-led-mode for HW errors
    [AirLyticsFrame_ESP.ino]
2022-11-02 Led now indicates that frame is trying to connect to a wifi
